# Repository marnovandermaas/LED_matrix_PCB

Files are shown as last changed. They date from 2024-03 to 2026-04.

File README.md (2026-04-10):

# PCB for driving an LED matrix

This PCB is meant to write and read from PMOD pins and drive an LED matrix based on these pins.
There will be a microcontroller that drives the LED matrix so it can also have an independent program to display arbitrary things on the matrix.

The PCB should be able to be powered externally as well as through a battery.
The reason to want to use a battery is that it can then be used as a conference badge to display a name on.

The PCB should connect to the Tiny Tapeout demo board, and specifically with [this factorizer design](https://github.com/marnovandermaas/tiny-factorizer/tree/main) that uses the bidirectional pins solely for output.

pinout

## Component Specs

Components should be through hole to ease soldering.

- RP Pico H
    - <https://www.raspberrypi.com/documentation/microcontrollers/raspberry-pi-pico.html>
    - 26 GPIO pins
    - Supply power to VSYS via a Schottky diode
        - ~2.3 V - 5.5 V
- LEDs (KINGBRIGHT TA07-11SEKWA)
    - <https://uk.farnell.com/kingbright/ta07-11sekwa/dot-matrix-0-7-cmn-anode-orange/dp/2080062>
    - Column anode (row cathode)
    - I_F = 10 mA, I_Fmax = 30 mA
    - V_F = 2 V_typ (@ I_F = 10mA)
    - R_7ma = (3.3 V - 2 V) / 7 mA = ~200 Ohm (186 Ohm)

## LED Multiplexing

Row-wise (one row at a time):

- 5 resistors (one per column)
- 5 LEDs max on one pin
    - 10 mA max per LED without transistor
- 7 phase update

Column-wise (one column at a time):

- 7 resistors (one per row)
- 7 LEDs max on one pin
    - 7 mA max per LED without transistor
- 5 phase update

Try using PIO to do the high-frequency stuff?
[PIO emulator](https://github.com/soundpaint/rp2040pio).

## Pins

12 GPIO for the LEDs.

7 GPIO for PMOD output to Tiny Tapeout.

5 GPIO pins for PMOD input from Tiny Tapeout.
Connect some to UART pins.

2 GPIO (or 1 ADC pin) for DIP switches.

Connect RUN pin to a normally-open momentary switch to GND to get a Reset button.

## PCB schematic and design

We'll probably use a cheap PCB manufacturer like: [JLC](https://jlcpcb.com/).
Previously I had also considerd [PCB way](https://www.pcbway.com/).

## Farnell

- 1x [Raspberry Pi Pico H](https://uk.farnell.com/raspberry-pi/raspberry-pi-pico-h/raspberry-pi-board-arm-cortex/dp/3996081)
- 1x [LED Matrix](https://uk.farnell.com/kingbright/ta07-11sekwa/dot-matrix-0-7-cmn-anode-orange/dp/2080062)
- 1x [Reset Switch](https://uk.farnell.com/te-connectivity-alcoswitch/1825910-3/tactile-switch-spst-0-05a-24v/dp/3406898)
- 2x [Schottky Diode](https://uk.farnell.com/stmicroelectronics/bat48/diode-schottky-small-signal/dp/9801472)
- 1x [DIP Switch](https://uk.farnell.com/te-connectivity/ade0204/switch-dil-2way/dp/1123936)
- 1x [Battery Holder](https://uk.farnell.com/keystone/3002/battery-smd-retainer-20mm/dp/1650693)
- 2x [PMOD Header](https://uk.farnell.com/amphenol-fci/10129382-912003blf/btb-conn-header-12pos-2row-2-54mm/dp/3497357)
- 2x [RPi Pico Socket](https://uk.farnell.com/samtec/ces-120-01-t-s/receptacle-2-54mm-single-20way/dp/1667525)
- 5x? [LED Resistors](https://uk.farnell.com/multicomp/mf25-200r/res-200r-1-250mw-axial-metal-film/dp/9341471) although may already have some.
- 4x? [Green LEDs](https://uk.farnell.com/broadcom-limited/hlmp-3950/led-5mm-green/dp/1003226)

## Shift registers

To make sure we can drive all the PMOD input and output, we were thinking it's a good idea to use a shift register to save GPIO pins on the Pico. One thing Elliot mentioned was it would be good to have one full PMOD directly connected to the GPIO so that UART still works.

8-bit parallel input to serial output: [TI SN74HC165N](https://uk.farnell.com/texas-instruments/sn74hc165n/ic-8bit-parallel-load-shift-regist/dp/3120856), 8 inputs with 1 ouput and 2 control signals.

Serial input to 8-bit parallel output: [TI SN74HC595N](https://uk.farnell.com/texas-instruments/sn74hc595n/shift-register-8bit-85deg-c-pdip/dp/3120865), 8 outputs with 1 input and 2 control signals.

Harry's tip: use 74-series logic to get good datasheets.

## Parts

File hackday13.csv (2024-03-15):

Reference | Value | Datasheet | Footprint | Qty | DNP
BT1 | 3V | ~ | Battery:BatteryHolder_Keystone_105_1x2430 | 1
D1 | red | ~ | LED_THT:LED_D5.0mm | 1
R1 | 1k | ~ | Resistor_THT:R_Axial_DIN0309_L9.0mm_D3.2mm_P12.70mm_Horizontal | 1

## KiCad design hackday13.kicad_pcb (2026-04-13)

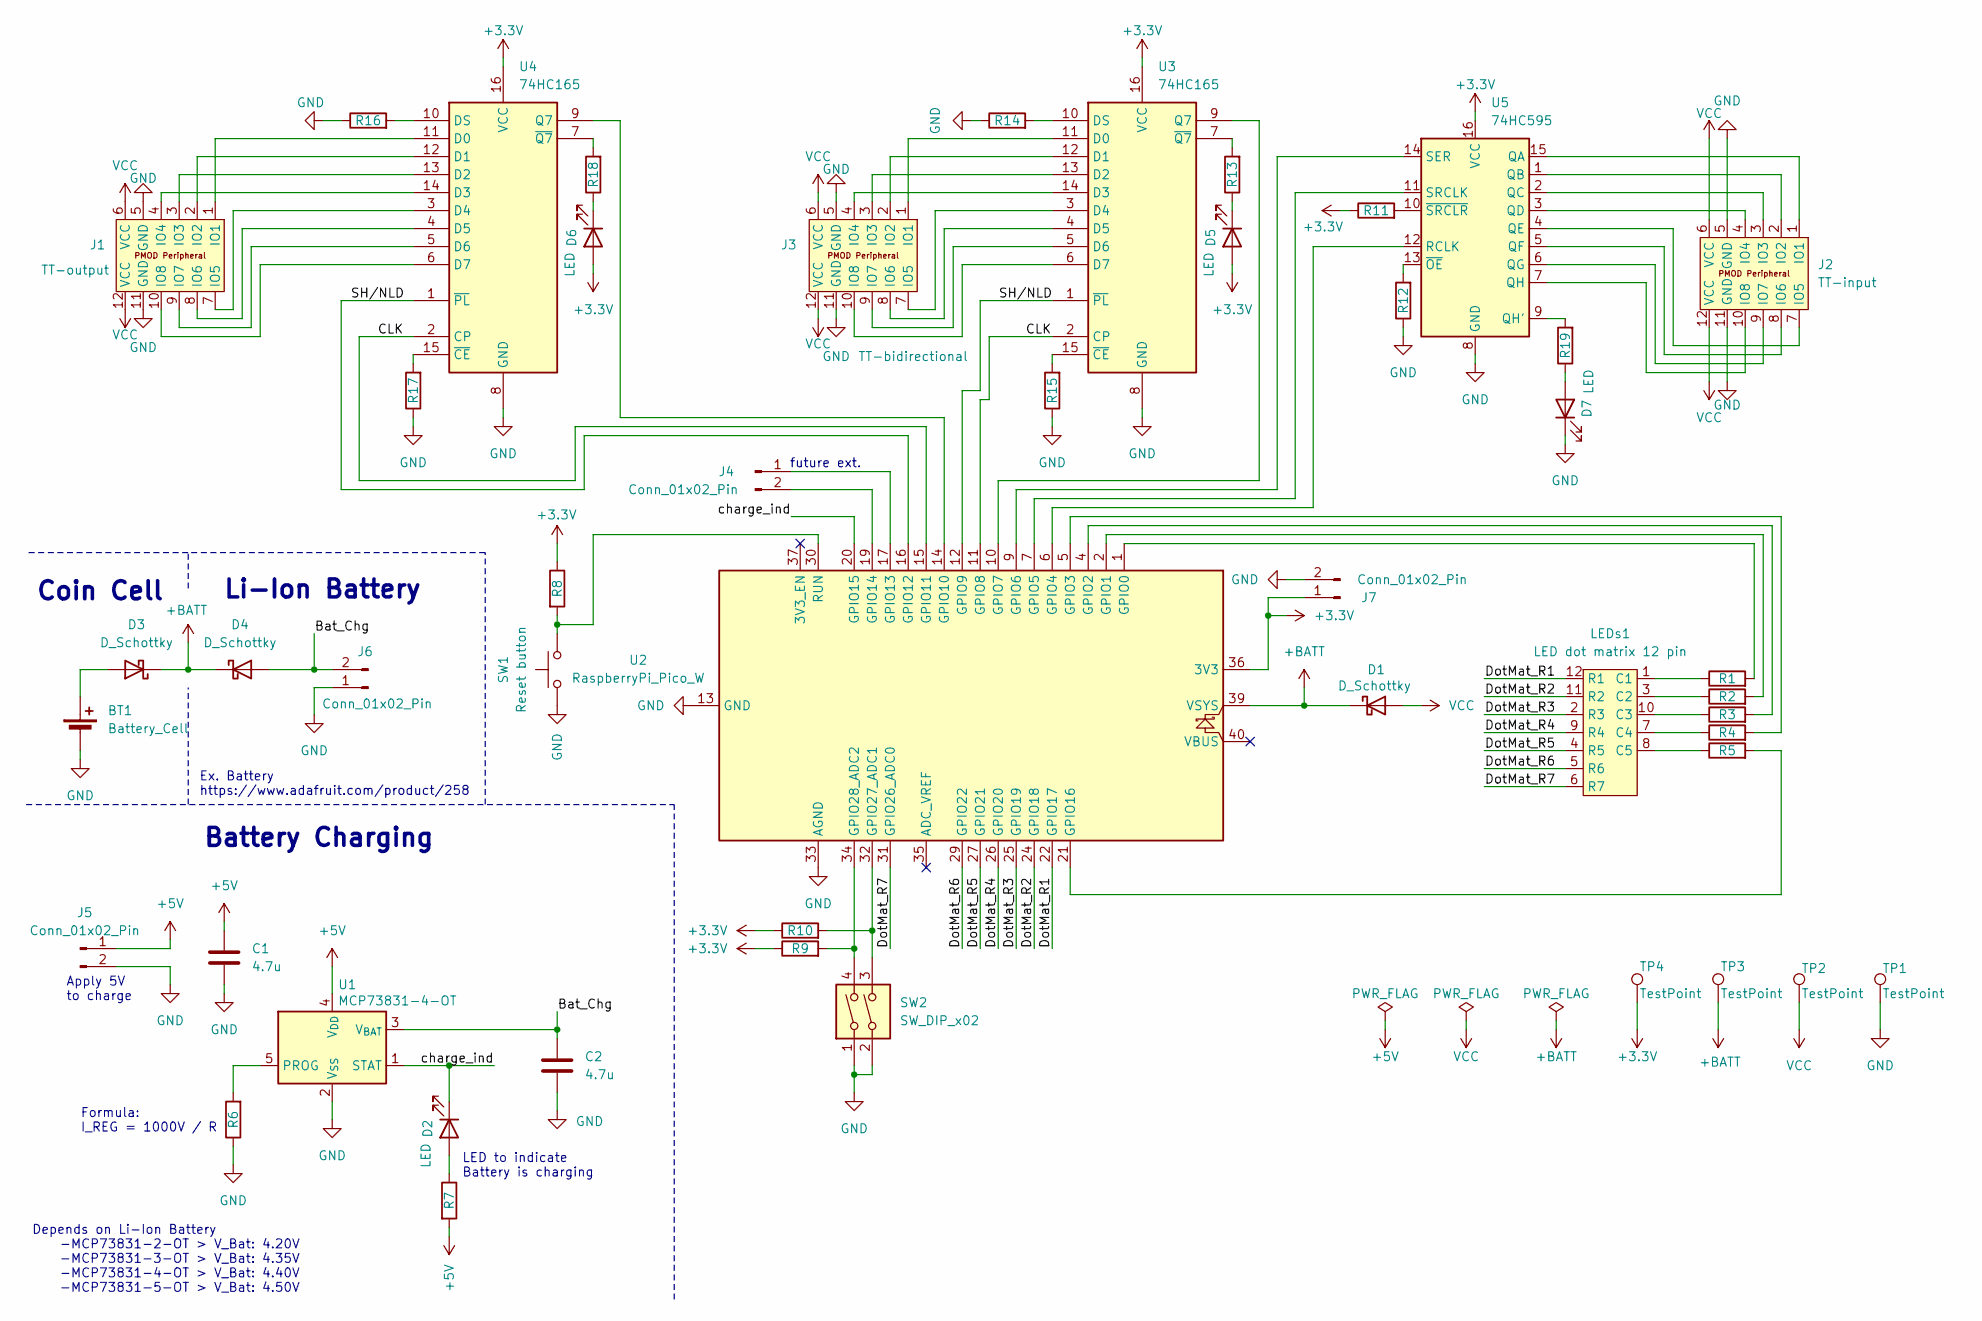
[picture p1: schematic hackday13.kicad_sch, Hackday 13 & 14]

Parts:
BT1: Battery_Cell; BatteryHolder_Keystone_3002_1x2032
C1, C2: 4.7u; C_Disc_D7.0mm_W2.5mm_P5.00mm
D1, D3, D4: D_Schottky; D_DO-35_SOD27_P7.62mm_Horizontal
D2, D5, D6, D7: LED; LED_D3.0mm
J1: TT-output; PinHeader_2x06_P2.54mm_PMODPeriph2B
J2: TT-input; PinHeader_2x06_P2.54mm_PMODPeriph2B
J3: TT-bidirectional; PinHeader_2x06_P2.54mm_PMODPeriph2B
J4, J5, J7: Conn_01x02_Pin; PinHeader_1x02_P2.54mm_Vertical
J6: Conn_01x02_Pin; JST_PH_B2B-PH-K_1x02_P2.00mm_Vertical
LEDs1: LED dot matrix 12 pin; LED_dot_matrix_TA07-11SEKWA
R1, R2, R3, R4, R5, R13, R18, R19: 200 Ohm; R_Axial_DIN0207_L6.3mm_D2.5mm_P10.16mm_Horizontal
R6: 2k; R_Axial_DIN0207_L6.3mm_D2.5mm_P10.16mm_Horizontal
R7: 1000 Ohm; R_Axial_DIN0207_L6.3mm_D2.5mm_P10.16mm_Horizontal
R8, R9, R10: 1k; R_Axial_DIN0207_L6.3mm_D2.5mm_P10.16mm_Horizontal
R11, R12, R14, R15, R16, R17: 0; R_Axial_DIN0207_L6.3mm_D2.5mm_P10.16mm_Horizontal
SW1: Reset button; SW_PUSH_6mm
SW2: SW_DIP_x02; SW_DIP_SPSTx02_Slide_9.78x7.26mm_W7.62mm_P2.54mm
TP1, TP2, TP3, TP4: TestPoint; TestPoint_Pad_D3.0mm
U1: MCP73831-4-OT; SOT-23-5
U2: RaspberryPi_Pico_W; RaspberryPi_Pico_Common
U3, U4: 74HC165; DIP-16_W7.62mm
U5: 74HC595; DIP-16_W7.62mm

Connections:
+3.3V: D5.2 (A), D6.2 (A), J7.1, R8.1, R9.1, R10.1, R11.1, TP4.1, U2.36 (3V3), U3.16 (VCC), U4.16 (VCC), U5.16 (VCC)
+5V: C1.1, J5.1, R7.2, U1.4 (V_{DD})
+BATT: D1.1 (K), D3.1 (K), D4.1 (K), TP3.1, U2.39 (VSYS)
/Bat_Chg: C2.1, D4.2 (A), J6.2, U1.3 (V_{BAT})
/CLK: U2.11 (GPIO8), U2.15 (GPIO11), U3.2 (CP), U4.2 (CP)
/DotMat_R1: LEDs1.12 (R1), U2.22 (GPIO17)
/DotMat_R2: LEDs1.11 (R2), U2.24 (GPIO18)
/DotMat_R3: LEDs1.2 (R3), U2.25 (GPIO19)
/DotMat_R4: LEDs1.9 (R4), U2.26 (GPIO20)
/DotMat_R5: LEDs1.4 (R5), U2.27 (GPIO21)
/DotMat_R6: LEDs1.5 (R6), U2.29 (GPIO22)
/DotMat_R7: LEDs1.6 (R7), U2.31 (GPIO26_ADC0)
/SH/NLD: U2.12 (GPIO9), U2.16 (GPIO12), U3.1 (~PL), U4.1 (~PL)
/charge_ind: D2.1 (K), U1.1 (STAT), U2.20 (GPIO15)
GND: BT1.2 (-), C1.2, C2.2, D7.1 (K), J1.5 (GND), J1.11 (GND), J2.5 (GND), J2.11 (GND), J3.5 (GND), J3.11 (GND), J5.2, J6.1, J7.2, R6.1, R12.1, R14.1, R15.1, R16.1, R17.1, SW1.1, SW2.1, SW2.2, TP1.1, U1.2 (V_{SS}), U2.3 (GND), U2.8 (GND), U2.13 (GND), U2.18 (GND), U2.23 (GND), U2.28 (GND), U2.33 (AGND), U2.38 (GND), U3.8 (GND), U4.8 (GND), U5.8 (GND)
unnamed: BT1.1 (+), D3.2 (A)
unnamed: D2.2 (A), R7.1
unnamed: D5.1 (K), R13.1
unnamed: D6.1 (K), R18.1
unnamed: D7.2 (A), R19.1
unnamed: J1.1 (IO1), U4.11 (D0)
unnamed: J1.2 (IO2), U4.12 (D1)
unnamed: J1.3 (IO3), U4.13 (D2)
unnamed: J1.4 (IO4), U4.14 (D3)
unnamed: J1.7 (IO5), U4.3 (D4)
unnamed: J1.8 (IO6), U4.4 (D5)
unnamed: J1.9 (IO7), U4.5 (D6)
unnamed: J1.10 (IO8), U4.6 (D7)
unnamed: J2.1 (IO1), U5.15 (QA)
unnamed: J2.2 (IO2), U5.1 (QB)
unnamed: J2.3 (IO3), U5.2 (QC)
unnamed: J2.4 (IO4), U5.3 (QD)
unnamed: J2.7 (IO5), U5.4 (QE)
unnamed: J2.8 (IO6), U5.5 (QF)
unnamed: J2.9 (IO7), U5.6 (QG)
unnamed: J2.10 (IO8), U5.7 (QH)
unnamed: J3.1 (IO1), U3.11 (D0)
unnamed: J3.2 (IO2), U3.12 (D1)
unnamed: J3.3 (IO3), U3.13 (D2)
unnamed: J3.4 (IO4), U3.14 (D3)
unnamed: J3.7 (IO5), U3.3 (D4)
unnamed: J3.8 (IO6), U3.4 (D5)
unnamed: J3.9 (IO7), U3.5 (D6)
unnamed: J3.10 (IO8), U3.6 (D7)
unnamed: J4.1, U2.17 (GPIO13)
unnamed: J4.2, U2.19 (GPIO14)
unnamed: LEDs1.1 (C1), R1.1
unnamed: LEDs1.3 (C2), R2.1
unnamed: LEDs1.10 (C3), R3.1
unnamed: LEDs1.7 (C4), R4.1
unnamed: LEDs1.8 (C5), R5.1
unnamed: R6.2, U1.5 (PROG)
unnamed: R1.2, U2.1 (GPIO0)
unnamed: R2.2, U2.2 (GPIO1)
unnamed: R3.2, U2.4 (GPIO2)
unnamed: R4.2, U2.5 (GPIO3)
unnamed: U2.6 (GPIO4), U5.12 (RCLK)
unnamed: U2.7 (GPIO5), U5.11 (SRCLK)
unnamed: U2.9 (GPIO6), U5.14 (SER)
unnamed: U2.10 (GPIO7), U3.9 (Q7)
unnamed: U2.14 (GPIO10), U4.9 (Q7)
unnamed: R5.2, U2.21 (GPIO16)
unnamed: R10.2, SW2.3, U2.32 (GPIO27_ADC1)
unnamed: R9.2, SW2.4, U2.34 (GPIO28_ADC2)
unnamed: R8.2, SW1.2, U2.30 (RUN)
unnamed: R14.2, U3.10 (DS)
unnamed: R15.2, U3.15 (~CE)
unnamed: R13.2, U3.7 (~Q7)
unnamed: R16.2, U4.10 (DS)
unnamed: R17.2, U4.15 (~CE)
unnamed: R18.2, U4.7 (~Q7)
unnamed: R19.2, U5.9 (QH')
unnamed: R12.2, U5.13 (~OE)
unnamed: R11.2, U5.10 (~SRCLR)
VCC: D1.2 (A), J1.6 (VCC), J1.12 (VCC), J2.6 (VCC), J2.12 (VCC), J3.6 (VCC), J3.12 (VCC), TP2.1

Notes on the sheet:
Battery Charging
LED to indicate Battery is charging
future ext.
Ex. Battery https://www.adafruit.com/product/258
Coin Cell
Apply 5V to charge
Li-Ion Battery
Depends on Li-Ion Battery -MCP73831-2-OT > V_Bat: 4.20V -MCP73831-3-OT > V_Bat: 4.35V -MCP73831-4-OT > V_Bat: 4.40V -MCP73831-5-OT > V_Bat: 4.50V
Formula: I_REG = 1000V / R

Board: 4 copper layers, 48 parts (0 on the bottom side), 75 nets, no tracks yet.

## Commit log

2024-03-15 First pass at adding PICO and connecting to Pmod
    [hackday13.kicad_sch]
2024-03-15 Add LED dot matrix schematic
    [hackday13.kicad_sch]
2024-03-15 Add footprint for LED dot matrix
    [hackday13.kicad_sch]
2024-03-15 Minor update to schematic
    [hackday13.kicad_pcb, hackday13.kicad_sch]
2024-07-12 Add MC14014B shift register
    Also make LED matrix have yellow background
2024-07-12 Connect up shift registers in schematic
    [hackday13.kicad_sch]
2024-07-12 Add schematics for shift regs
    Some other cleanup like wires and component names.
    [hackday13.kicad_sch]
2024-07-12 Label disconnects and power to resolve ERC checks
    [hackday13.kicad_sch]
2024-07-12 Minor layout improvements
    [hackday13.kicad_sch]
2024-07-12 Incomplete attempt at PCB
    [hackday13.kicad_pcb]
2024-07-16 Make PCB more compact and remove more ground lines
    [hackday13.kicad_pcb]
2026-04-10 [proj/schematic] Update Project to KiCad Vers. 9.0.X + add Li-Ion Charger to schematic
    [hackday13.kicad_sch]
2026-04-10 [layout] Start with new 4-L layout
    [hackday13.kicad_pcb, hackday13.kicad_sch]
2026-04-10 Through hole shift registers
2026-04-10 Component through hole comment
2026-04-10 [doc] LEDs added and component list
2026-04-13 Update schematic
    [hackday13.kicad_sch]
2026-04-13 Add initial placement
    [hackday13.kicad_pcb, hackday13.kicad_sch]
2026-04-15 Hackday 19 added to title
    [hackday13.kicad_sch]
